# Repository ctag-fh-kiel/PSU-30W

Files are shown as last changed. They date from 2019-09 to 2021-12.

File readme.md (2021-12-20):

# Eurorack power supply unit 30W with DCDC converter
- Uses 9-12V 3A power adaptor (e.g. from LED power supply)
- Converts +12V in to +/- 12V and +5V out
- Can be used fully isolated

# Includes 3D PLA printed housing
- Use Eurorack_Case_3D_Print_PLA_gcode.zip directly in your 3D printer (attention, veeeery long print duration), tested on Prusa i3

# Includes lasercut case (85hp) with lid
- created using https://www.festi.info/boxes.py/ and https://inkscape.org/
- Material: 4mm thick wood or PMMA (70 x 46 cm)
- Module support rails: APRA 241 (85hp)

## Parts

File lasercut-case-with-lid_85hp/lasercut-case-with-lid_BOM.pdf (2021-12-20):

Tabelle1

Beschreibung | Art.Nr. | VPE

Bürklin.de
Standard Modulschiene 85TE 431,9mm | 82H350 | 1 Stück

Reichelt.de
Distanzhülsen, Metall, 6-Kant, M3, 5mm | DA 5MM | 1 Stück
Sechskantmuttern, M3, 100 Stück | SK M3 | 100 Stück
Zylinderkopfschrauben, Schlitz, M3, 8 mm, 200 Stück | SZK M3X8-200 | 200 Stück
Gewindestreifen M2,5 4 Stück | BGT 384-2 | 4 Stück
Zylinderkopfschrauben, Schlitz, M2,5, 10 mm | SZK M2,5X10-200 | 200 Stück
PAN Head Schrauben, Kreuzschlitz, PZD, M4, 16mm, 50 Stück SKL M4X16-50 | 50 Stück

Tabelle1

Preis/ VPE | Anzahl für ein Case
5,90 € | 2
0,11 € | 8
1,17 € | 8
2,50 € | 8
7,90 € | 2
3,50 € | Max. 160
1,90 € | 4

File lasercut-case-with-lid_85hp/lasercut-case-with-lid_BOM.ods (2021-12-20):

Beschreibung | Art.Nr. | VPE | Preis/ VPE | Anzahl für ein Case
Bürklin.de
Standard Modulschiene 85TE 431,9mm | 82H350 | 1 Stück | 5,90 € | 2
Reichelt.de
Distanzhülsen, Metall, 6-Kant, M3, 5mm | DA 5MM | 1 Stück | 0,11 € | 8
Sechskantmuttern, M3, 100 Stück | SK M3 | 100 Stück | 1,17 € | 8
Zylinderkopfschrauben, Schlitz, M3, 8 mm, 200 Stück | SZK M3X8-200 | 200 Stück | 2,50 € | 8
Gewindestreifen M2,5 4 Stück | BGT 384-2 | 4 Stück | 7,90 € | 2
Zylinderkopfschrauben, Schlitz, M2,5, 10 mm | SZK M2,5X10-200 | 200 Stück | 3,50 € | Max. 160
PAN Head Schrauben, Kreuzschlitz, PZD, M4, 16mm, 50 Stück | SKL M4X16-50 | 50 Stück | 1,90 € | 4

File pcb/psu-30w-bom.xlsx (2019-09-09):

Designator | Package | Quantity | Designation | Supplier and ref
JP2 | PinHeader_1x03_P2.54mm_Vertical | 1 | PWR_SEL | Pin header 2.54mm
JP1 | PinHeader_1x02_P2.54mm_Vertical | 1 | Isolation | Pin header 2.54mm
J1 | PJ-059A | 1 | Barrel_Jack | PJ-059A (https://www.mouser.de/ProductDetail/CUI/PJ-059A)
R4 | R_0805_2012Metric_Pad1.15x1.40mm_HandSolder | 1 | 180 | Standard 0805 5%
R3,R2,R1 | R_0805_2012Metric_Pad1.15x1.40mm_HandSolder | 3 | 560 | Standard 0805 5%
J101 | Molex_KK-254_AE-6410-04A_1x04_P2.54mm_Vertical | 1 | SWITCH
DC101 | DKA30A-12 | 1 | DKA30A-12 | DKA30A-12
U1 | SIP3_11.6x8.5mm | 1 | R-78E5.0-1.0 | R-78E5.0-1.0
C3 | CP_Elec_10x10 | 1 | 22u | Any 22uF, can be ommited
J10,J2,J3,J4,J5,J6,J7,J8,J9,J11,J12,J13,J14,J15,J16,J17 | PinHeader_2x08_P2.54mm_Vertical | 16 | ~ | Pin header 2.54mm Dual Row
D1 | D_DO-201AD_P15.24mm_Horizontal | 1 | 1N5402 | 1N5402
D2,D3,D4,D5 | LED_D5.0mm | 4 | LED | Any 5mm LED

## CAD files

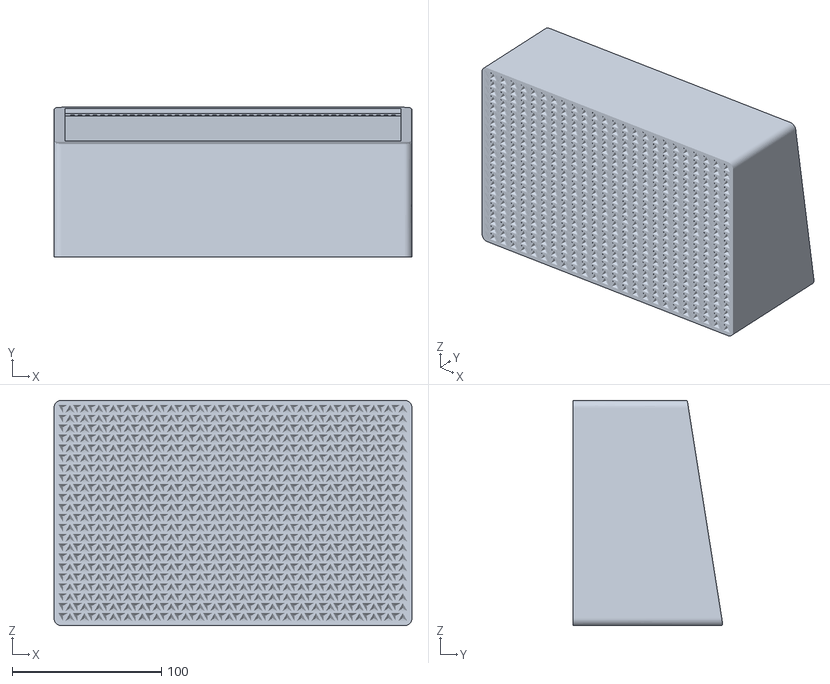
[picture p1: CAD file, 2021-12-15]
3d-printed-housing/Eurorack_Case_3D_Print_v1.3.STL
240.0 x 100.2 x 151.0

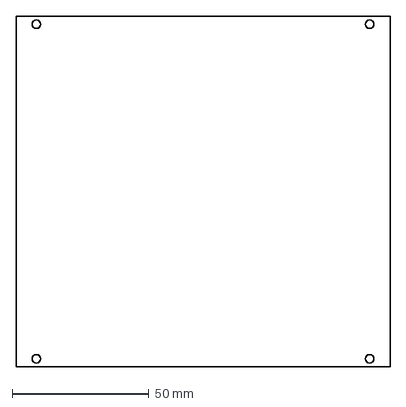
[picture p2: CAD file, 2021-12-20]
lasercut-case-with-lid_85hp/blind-panel_27hp.dxf
136.8 x 128.4 mm

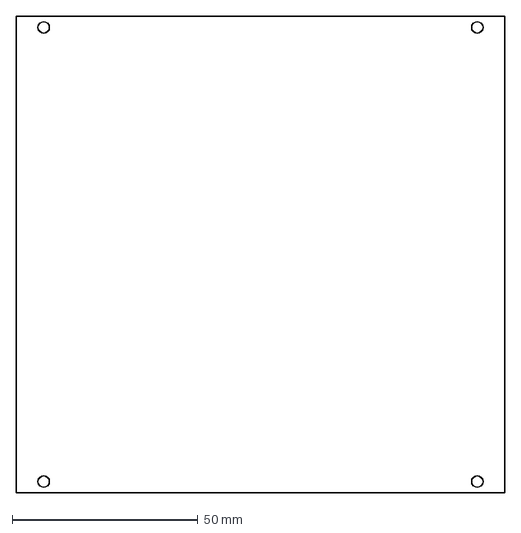
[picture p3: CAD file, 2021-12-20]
lasercut-case-with-lid_85hp/blind-panel_26hp.dxf
131.7 x 128.4 mm

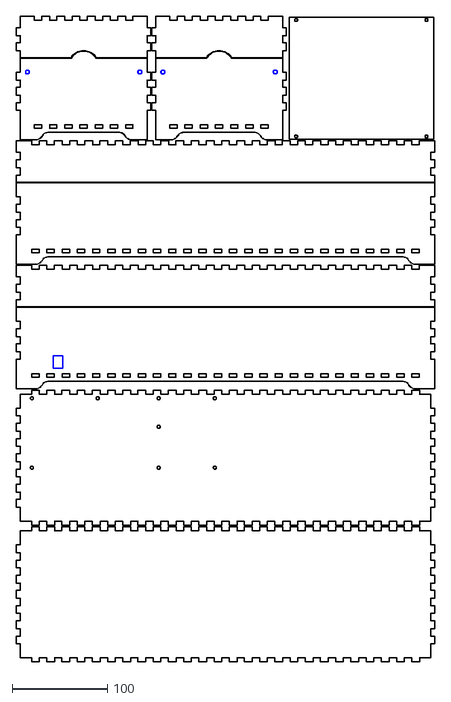
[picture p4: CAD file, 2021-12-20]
lasercut-case-with-lid_85hp/case_85HP_with_Lid_0.1bc.dxf
440.2 x 678.9

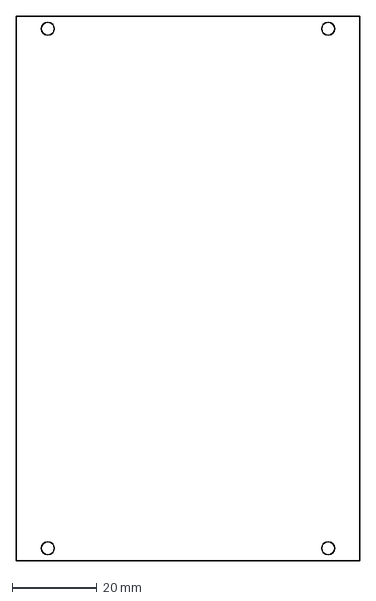
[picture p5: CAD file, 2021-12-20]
lasercut-case-with-lid_85hp/blind-panel_16hp.dxf
80.9 x 128.4 mm

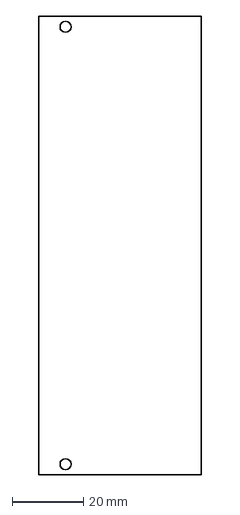
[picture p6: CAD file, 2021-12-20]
lasercut-case-with-lid_85hp/blind-panel_9hp.dxf
45.4 x 128.4 mm

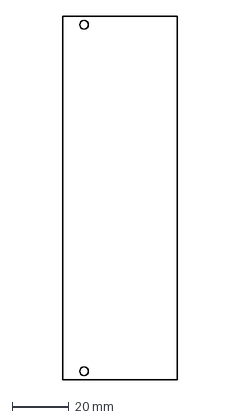
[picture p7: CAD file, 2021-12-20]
lasercut-case-with-lid_85hp/blind-panel_8hp.dxf
40.3 x 128.4 mm

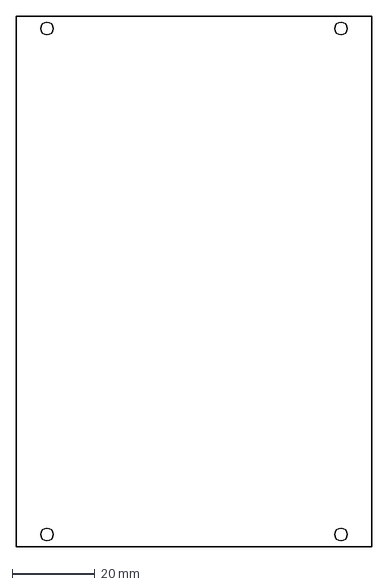
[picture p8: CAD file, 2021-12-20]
lasercut-case-with-lid_85hp/blind-panel_17hp.dxf
86.0 x 128.4 mm

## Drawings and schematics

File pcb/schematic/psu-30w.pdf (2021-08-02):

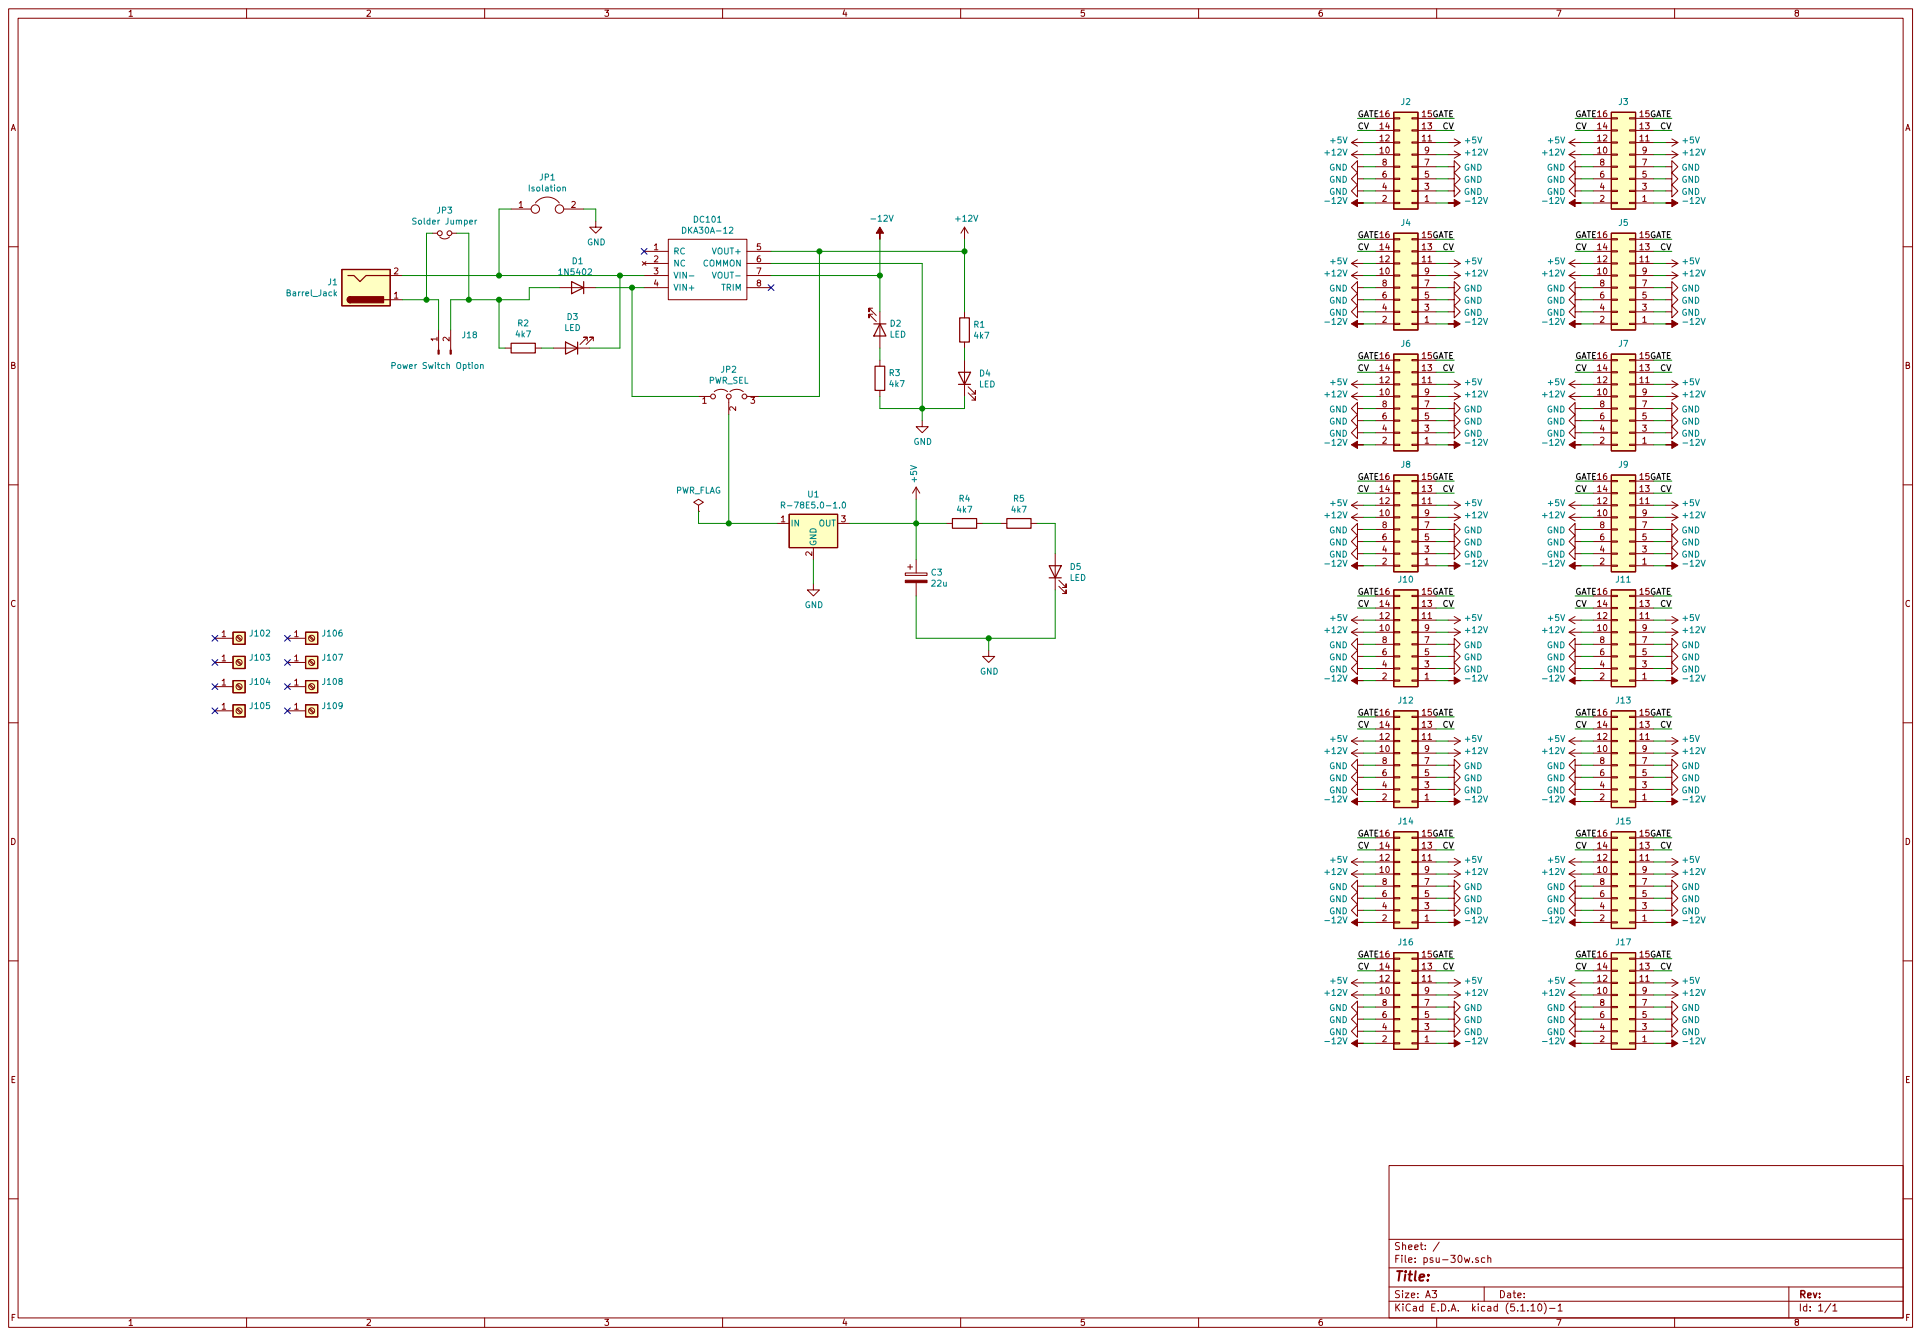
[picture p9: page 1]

+12V GND GND GND GND

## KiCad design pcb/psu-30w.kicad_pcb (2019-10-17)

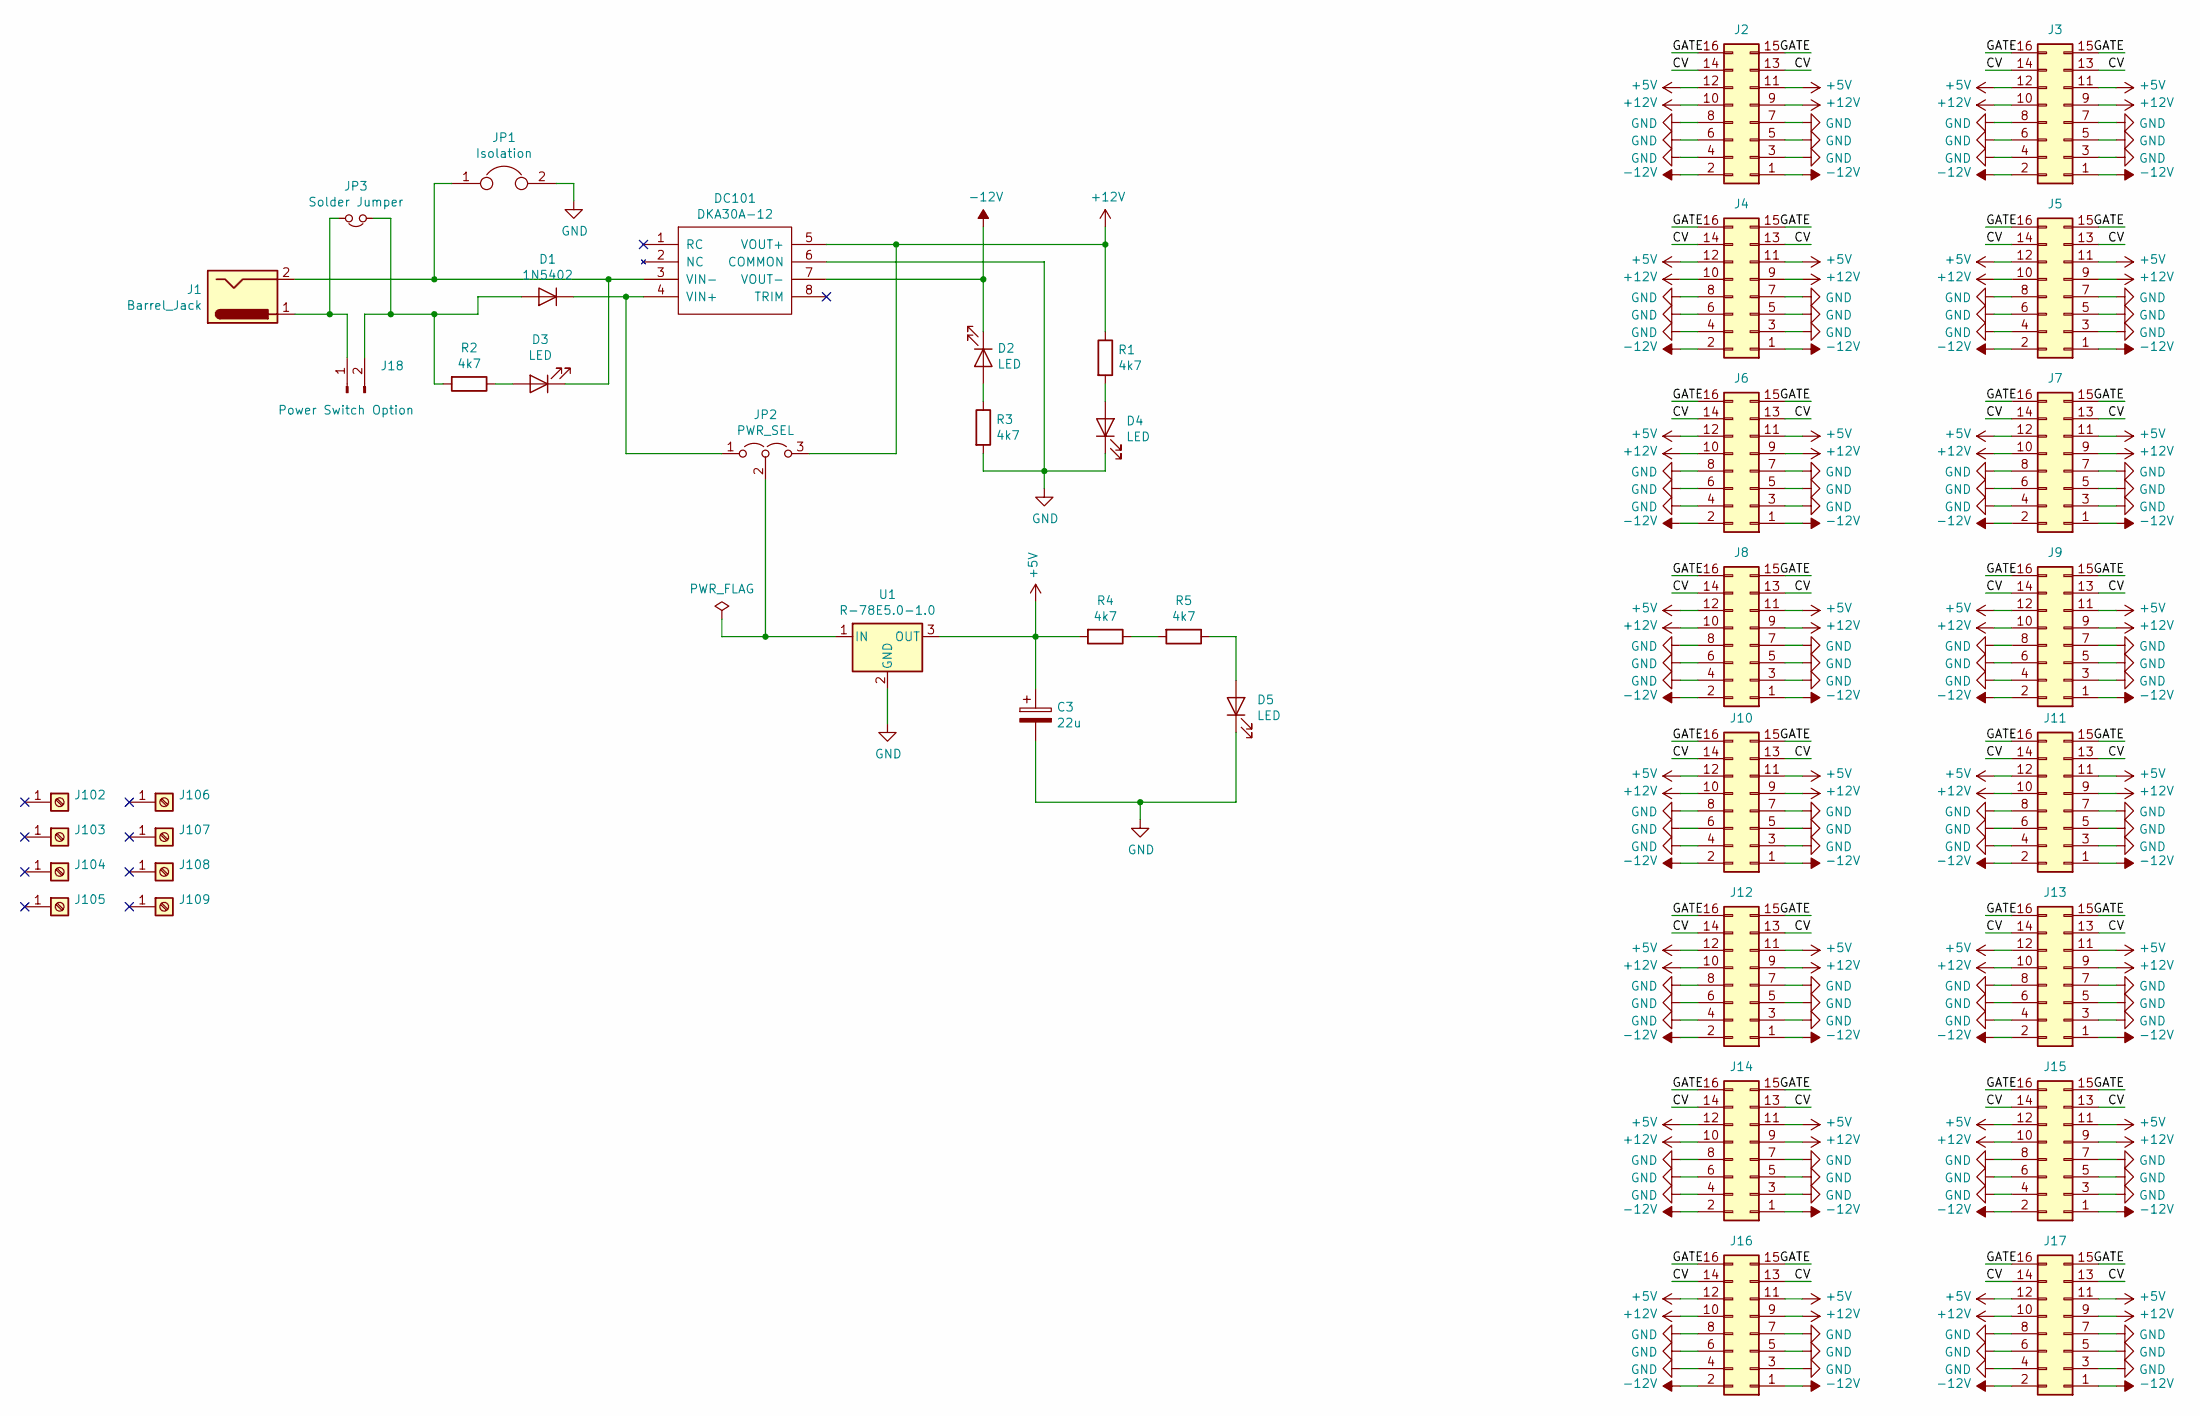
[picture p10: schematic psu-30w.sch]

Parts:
C3: 22u; CP_Elec_10x10
D1: 1N5402; D_DO-201AD_P15.24mm_Horizontal
D2, D3, D4, D5: LED; LED_D5.0mm
DC101: DKA30A-12
J1: Barrel_Jack; PJ-059A
J2, J3, J4, J5, J6, J7, J8, J9, J10, J11, J12, J13, J14, J15, J16, J17: PinHeader_2x08_P2.54mm_Vertical
J18: Power Switch Option; PinHeader_1x02_P2.54mm_Vertical
J102, J103, J104, J105, J106, J107, J108, J109: MountingHole_3.2mm_M3_DIN965_Pad
JP1: Isolation; PinHeader_1x02_P2.54mm_Vertical
JP2: PWR_SEL; PinHeader_1x03_P2.54mm_Vertical
JP3: Solder Jumper; SolderJumper-2_P1.3mm_Open_TrianglePad1.0x1.5mm
R1, R2, R3, R4, R5: 4k7; R_0805_2012Metric_Pad1.15x1.40mm_HandSolder
U1: R-78E5.0-1.0; SIP3_11.6x8.5mm

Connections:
+5V: C3.1, J2.11, J2.12, J3.11, J3.12, J4.11, J4.12, J5.11, J5.12, J6.11, J6.12, J7.11, J7.12, J8.11, J8.12, J9.11, J9.12, J10.11, J10.12, J11.11, J11.12, J12.11, J12.12, J13.11, J13.12, J14.11, J14.12, J15.11, J15.12, J16.11, J16.12, J17.11, J17.12, R4.2, U1.3 (OUT)
+12V: DC101.5 (VOUT+), J2.9, J2.10, J3.9, J3.10, J4.9, J4.10, J5.9, J5.10, J6.9, J6.10, J7.9, J7.10, J8.9, J8.10, J9.9, J9.10, J10.9, J10.10, J11.9, J11.10, J12.9, J12.10, J13.9, J13.10, J14.9, J14.10, J15.9, J15.10, J16.9, J16.10, J17.9, J17.10, JP2.3 (B), R1.1
-12V: D2.1 (K), DC101.7 (VOUT-), J2.1, J2.2, J3.1, J3.2, J4.1, J4.2, J5.1, J5.2, J6.1, J6.2, J7.1, J7.2, J8.1, J8.2, J9.1, J9.2, J10.1, J10.2, J11.1, J11.2, J12.1, J12.2, J13.1, J13.2, J14.1, J14.2, J15.1, J15.2, J16.1, J16.2, J17.1, J17.2
/CV: J2.13, J2.14, J3.13, J3.14, J4.13, J4.14, J5.13, J5.14, J6.13, J6.14, J7.13, J7.14, J8.13, J8.14, J9.13, J9.14, J10.13, J10.14, J11.13, J11.14, J12.13, J12.14, J13.13, J13.14, J14.13, J14.14, J15.13, J15.14, J16.13, J16.14, J17.13, J17.14
/GATE: J2.15, J2.16, J3.15, J3.16, J4.15, J4.16, J5.15, J5.16, J6.15, J6.16, J7.15, J7.16, J8.15, J8.16, J9.15, J9.16, J10.15, J10.16, J11.15, J11.16, J12.15, J12.16, J13.15, J13.16, J14.15, J14.16, J15.15, J15.16, J16.15, J16.16, J17.15, J17.16
GND: C3.2, D4.1 (K), D5.1 (K), DC101.6 (COMMON), J2.3, J2.4, J2.5, J2.6, J2.7, J2.8, J3.3, J3.4, J3.5, J3.6, J3.7, J3.8, J4.3, J4.4, J4.5, J4.6, J4.7, J4.8, J5.3, J5.4, J5.5, J5.6, J5.7, J5.8, J6.3, J6.4, J6.5, J6.6, J6.7, J6.8, J7.3, J7.4, J7.5, J7.6, J7.7, J7.8, J8.3, J8.4, J8.5, J8.6, J8.7, J8.8, J9.3, J9.4, J9.5, J9.6, J9.7, J9.8, J10.3, J10.4, J10.5, J10.6, J10.7, J10.8, J11.3, J11.4, J11.5, J11.6, J11.7, J11.8, J12.3, J12.4, J12.5, J12.6, J12.7, J12.8, J13.3, J13.4, J13.5, J13.6, J13.7, J13.8, J14.3, J14.4, J14.5, J14.6, J14.7, J14.8, J15.3, J15.4, J15.5, J15.6, J15.7, J15.8, J16.3, J16.4, J16.5, J16.6, J16.7, J16.8, J17.3, J17.4, J17.5, J17.6, J17.7, J17.8, JP1.2, R3.2, U1.2 (GND)
unnamed: D1.1 (K), DC101.4 (VIN+), JP2.1 (A)
unnamed: D1.2 (A), J18.2, JP3.1, R2.2
unnamed: D2.2 (A), R3.1
unnamed: D3.1 (K), DC101.3 (VIN-), J1.2, JP1.1
unnamed: D3.2 (A), R2.1
unnamed: D4.2 (A), R1.2
unnamed: D5.2 (A), R5.1
unnamed: J1.1, J18.1, JP3.2
unnamed: JP2.2 (C), U1.1 (IN)
unnamed: R4.1, R5.2

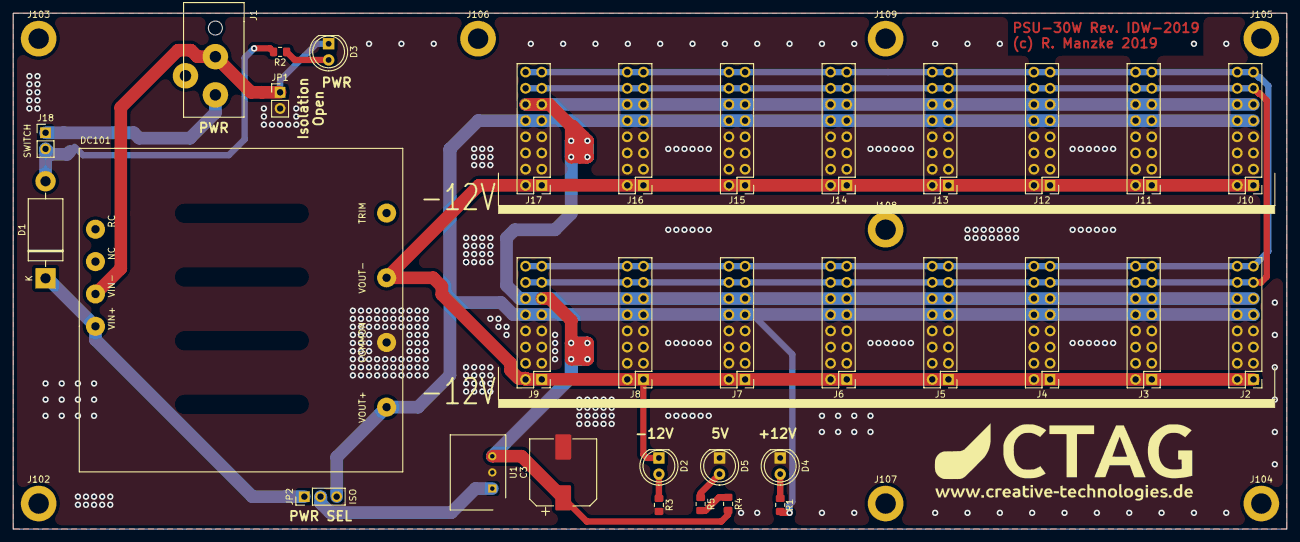
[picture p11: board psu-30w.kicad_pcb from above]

Board: 2 copper layers, 200.0 x 81.0 mm, 42 parts (1 on the bottom side), 16 nets.

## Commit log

2019-04-05 production files rev b
    [psu-30w-B_Cu.gbl, psu-30w-B_Mask.gbs, psu-30w-B_SilkS.gbo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]
2019-09-09 added readme and bom
    [psu-30w-bom.xlsx, psu-30w.csv]
2019-10-15 adaptations + simplifications
    [psu-30w.kicad_pcb, psu-30w.sch]
2019-10-17 order version
    [psu-30w-B_Cu.gbl, psu-30w-B_Mask.gbs, psu-30w-B_SilkS.gbo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]
2021-08-02 schematic pdf
2021-12-07 directory cleaned up
    [psu-30w-bom.xlsx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]
2021-12-15 .stl file for housing added...
    [Eurorack_Case_3D_Print_v1.3.STL]
2021-12-20 added files for lasercut case
    [blind-panel_16hp.dxf, blind-panel_17hp.dxf, blind-panel_26hp.dxf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]
2022-05-11 added interactive BOM
